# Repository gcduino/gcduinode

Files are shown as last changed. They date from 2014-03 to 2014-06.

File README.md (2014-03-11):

GCDuiNODE
=========

© 2014 Steve Dalton & Rod Christian

GCDuiNODE is a [GCDuino](https://github.com/gctechshop/gcduino) but running at 3.3V and includes a whole load of ports for  Networking modules. It was created by [Rod Christian](http://github.com/Rod-Refactor) and [Steve Dalton](http://github.com/spidie) of [Gold Coast TechSpace](http://gctechspace.org).

How to checkout this code
-------------------------

    git clone git@github.com:gctechshop/gcduinode.git

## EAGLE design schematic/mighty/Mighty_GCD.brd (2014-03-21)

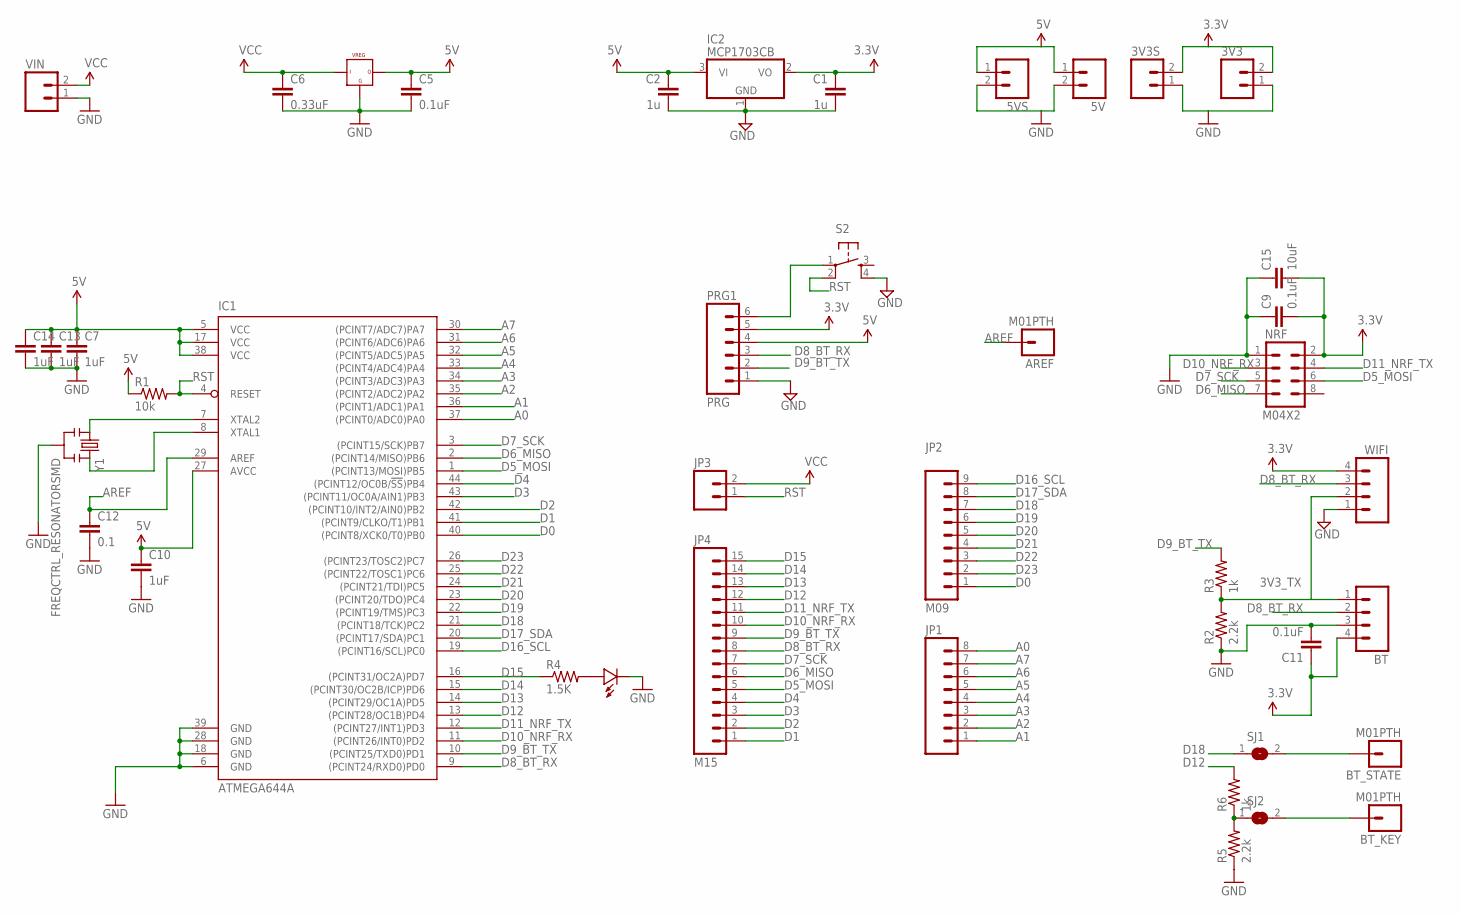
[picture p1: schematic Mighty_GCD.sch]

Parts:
3V3, 3V3S, 5V, 5VS: M02PTH; 1X02
AREF: M01PTH; 1X01
BT: M04PTH; 1X04
BT_KEY: M01PTH; 1X01
BT_STATE: M01PTH; 1X01
C1, C2: 1u; 0805
C5, C9, C11: 0.1uF; 0805
C6: 0.33uF; 0805
C7, C10, C13, C14: 1uF; 0805
C12: 0.1; 0805
C15: 10uF; 0805
IC1: ATMEGA644A; TQFP44
IC2: MCP1703CB; SOT23
JP1: M081X08; 1X08
JP2: M09; 1X09
JP3: M02PTH; 1X02
JP4: M15; 1X15
NRF: M04X2; 2X4
PRG1: PRG; 1X06
R1: 10k; 0805
R2, R5: 2.2k; 0805
R3, R6: 1k; 0805
R4: 1.5K; 0805
S2: TAC_SWITCHSMD; TACTILE_SWITCH_SMD
SJ1, SJ2: SJ
U$5: VREG_5V; DPACK
U$14: LED0805; 0805-LED
VIN: M02PTH; 1X02
WIFI: M04PTH; 1X04
Y1: FREQCTRL_RESONATORSMD; FREQCTRL_RESONATOR-SMD

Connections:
3.3V: 3V3.2, 3V3S.2, BT.4, C1.1, C9.2, C11.1, C15.2, IC2.2 (VO), NRF.2, PRG1.5, WIFI.4
3V3_TX: BT.1, R2.2, R3.1, WIFI.2
5V: 5V.1, 5VS.1, C2.1, C5.1, C7.1, C10.1, C13.1, C14.1, IC1.5 (VCC), IC1.17 (VCC), IC1.27 (AVCC), IC1.38 (VCC), IC2.3 (VI), PRG1.4, R1.1, U$5.3
A0: IC1.37 ((PCINT0/ADC0)PA0), JP1.8
A1: IC1.36 ((PCINT1/ADC1)PA1), JP1.1
A2: IC1.35 ((PCINT2/ADC2)PA2), JP1.2
A3: IC1.34 ((PCINT3/ADC3)PA3), JP1.3
A4: IC1.33 ((PCINT4/ADC4)PA4), JP1.4
A5: IC1.32 ((PCINT5/ADC5)PA5), JP1.5
A6: IC1.31 ((PCINT6/ADC6)PA6), JP1.6
A7: IC1.30 ((PCINT7/ADC7)PA7), JP1.7
AREF: AREF.1, C12.1, IC1.29 (AREF)
D0: IC1.40 ((PCINT8/XCK0/T0)PB0), JP2.1
D1: IC1.41 ((PCINT9/CLKO/T1)PB1), JP4.1
D2: IC1.42 ((PCINT10/INT2/AIN0)PB2), JP4.2
D3: IC1.43 ((PCINT11/OC0A/AIN1)PB3), JP4.3
D4: IC1.44 ((PCINT12/OC0B/!SS!)PB4), JP4.4
D5_MOSI: IC1.1 ((PCINT13/MOSI)PB5), JP4.5, NRF.6
D6_MISO: IC1.2 ((PCINT14/MISO)PB6), JP4.6, NRF.7
D7_SCK: IC1.3 ((PCINT15/SCK)PB7), JP4.7, NRF.5
D8_BT_RX: BT.2, IC1.9 ((PCINT24/RXD0)PD0), JP4.8, PRG1.3, WIFI.3
D9_BT_TX: IC1.10 ((PCINT25/TXD0)PD1), JP4.9, PRG1.2, R3.2
D10_NRF_RX: IC1.11 ((PCINT26/INT0)PD2), JP4.10, NRF.3
D11_NRF_TX: IC1.12 ((PCINT27/INT1)PD3), JP4.11, NRF.4
D12: IC1.13 ((PCINT28/OC1B)PD4), JP4.12, R6.2
D13: IC1.14 ((PCINT29/OC1A)PD5), JP4.13
D14: IC1.15 ((PCINT30/OC2B/ICP)PD6), JP4.14
D15: IC1.16 ((PCINT31/OC2A)PD7), JP4.15, R4.1
D16_SCL: IC1.19 ((PCINT16/SCL)PC0), JP2.9
D17_SDA: IC1.20 ((PCINT17/SDA)PC1), JP2.8
D18: IC1.21 ((PCINT18/TCK)PC2), JP2.7, SJ1.1
D19: IC1.22 ((PCINT19/TMS)PC3), JP2.6
D20: IC1.23 ((PCINT20/TDO)PC4), JP2.5
D21: IC1.24 ((PCINT21/TDI)PC5), JP2.4
D22: IC1.25 ((PCINT22/TOSC1)PC6), JP2.3
D23: IC1.26 ((PCINT23/TOSC2)PC7), JP2.2
GND: 3V3.1, 3V3S.1, 5V.2, 5VS.2, BT.3, C1.2, C2.2, C5.2, C6.2, C7.2, C9.1, C10.2, C11.2, C12.2, C13.2, C14.2, C15.1, IC1.6 (GND), IC1.18 (GND), IC1.28 (GND), IC1.39 (GND), IC2.1 (GND), NRF.1, PRG1.1, R2.1, R5.1, S2.4, U$5.2, U$14.MINUS, VIN.1, WIFI.1, Y1.2
unnamed: R4.2, U$14.PLUS
unnamed: IC1.7 (XTAL2), Y1.1
unnamed: IC1.8 (XTAL1), Y1.3
unnamed: PRG1.6, S2.1
unnamed: BT_STATE.1, SJ1.2
unnamed: BT_KEY.1, SJ2.2
unnamed: R5.2, R6.1, SJ2.1
RST: IC1.4 (RESET), JP3.1, R1.2, S2.2
VCC: C6.1, JP3.2, U$5.1, VIN.2

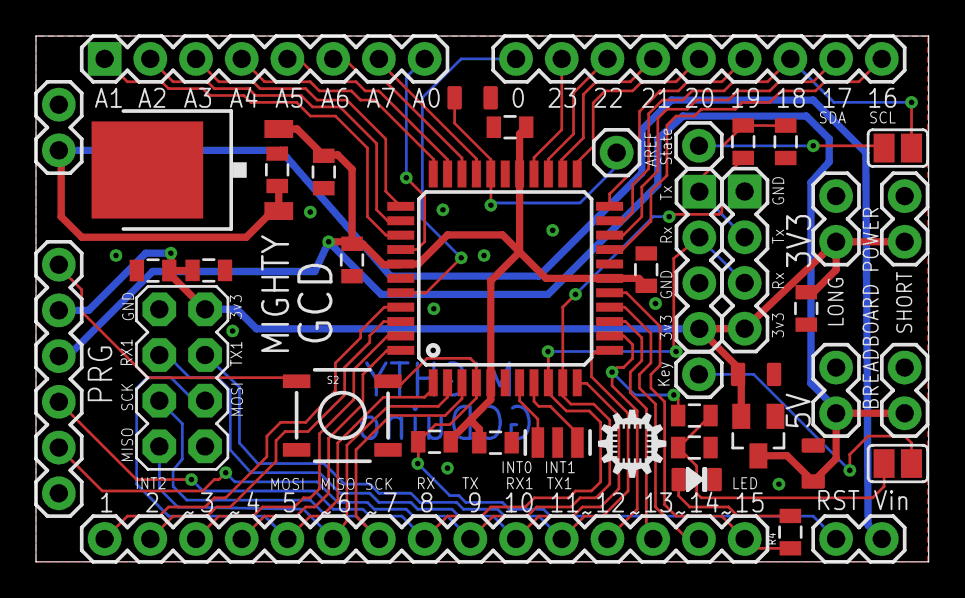
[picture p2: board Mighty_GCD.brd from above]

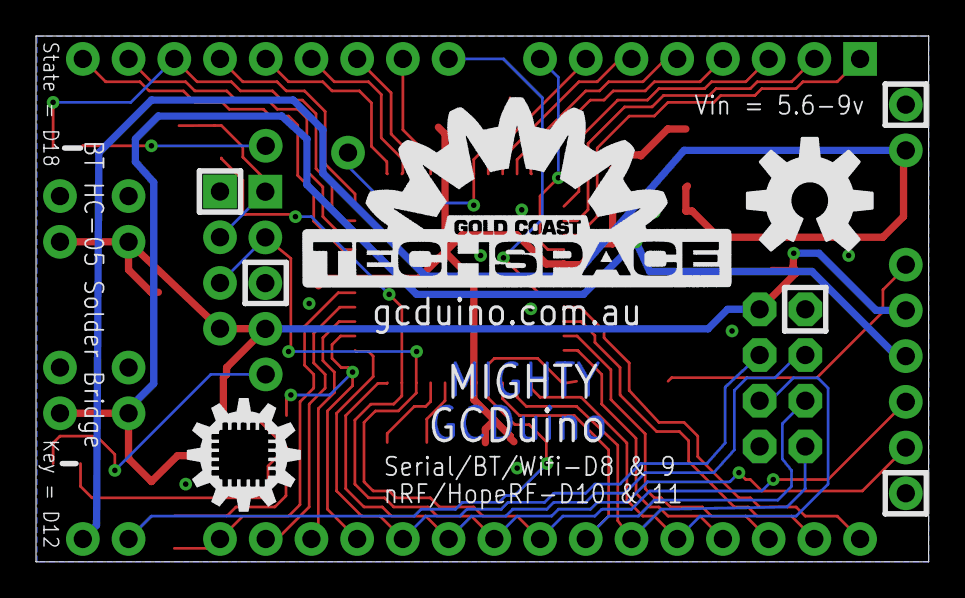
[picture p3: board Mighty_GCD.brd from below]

Board: 2 copper layers, 49.6 x 29.2 mm, 46 parts (3 on the bottom side), 46 nets.

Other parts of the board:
U$1: ID_LOGO_X0.25
U$2: GCTS_X0.5_TSILK
U$3: OSHW-LOGO-L
U$4: ID_LOGO_X0.15

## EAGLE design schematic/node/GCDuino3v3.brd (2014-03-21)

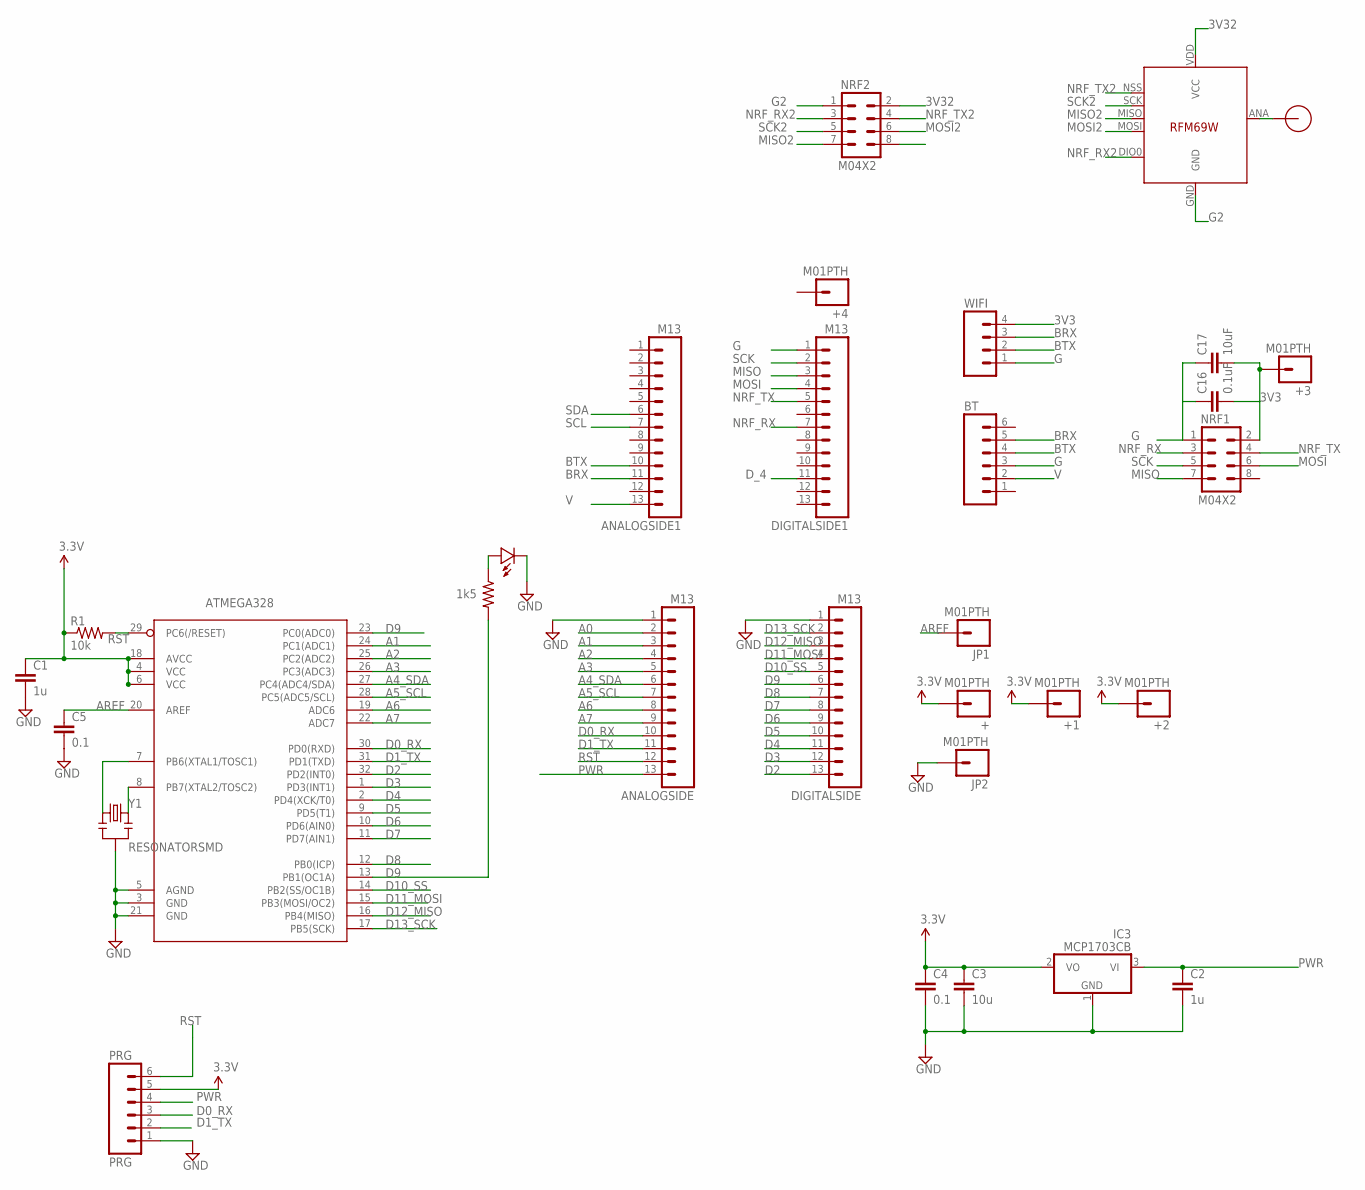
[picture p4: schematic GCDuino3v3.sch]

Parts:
+, +1, +2, +3, +4: M01PTH; 1X01
ANALOGSIDE, ANALOGSIDE1: M13; 1X13
ATMEGA328: ATMega-328; TQFP32-08
BT: M06SIP; 1X06
C1, C2: 1u; 0805
C3: 10u; 0805-CAP
C4, C5: 0.1; 0805
C16: 0.1uF; 0805
C17: 10uF; 0805
DIGITALSIDE, DIGITALSIDE1: M13; 1X13
IC3: MCP1703CB; SOT23
JP1, JP2: M01PTH; 1X01
NRF1, NRF2: M04X2; 2X4
PRG: PRG; 1X06
R1: 10k; 0805
R2: 1k5; 0805
U$2: LED0805; 0805-LED
U$5: RFM69; RFM69W-MINPADS
U$8: RFM12B_ANTENNA; RFM12B-ANTENNA
WIFI: M04PTH; 1X04
Y1: RESONATORSMD; RESONATOR-SMD

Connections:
3.3V: +.1, +1.1, +2.1, ATMEGA328.4 (VCC), ATMEGA328.6 (VCC), ATMEGA328.18 (AVCC), C1.1, C3.1, C4.1, IC3.2 (VO), PRG.5, R1.1
3V3: +3.1, C16.2, C17.2, NRF1.2, WIFI.4
3V32: NRF2.2, U$5.VDD (VCC)
A0: ANALOGSIDE.2, ATMEGA328.23 (PC0(ADC0))
A1: ANALOGSIDE.3, ATMEGA328.24 (PC1(ADC1))
A2: ANALOGSIDE.4, ATMEGA328.25 (PC2(ADC2))
A3: ANALOGSIDE.5, ATMEGA328.26 (PC3(ADC3))
A4_SDA: ANALOGSIDE.6, ATMEGA328.27 (PC4(ADC4/SDA))
A5_SCL: ANALOGSIDE.7, ATMEGA328.28 (PC5(ADC5/SCL))
A6: ANALOGSIDE.8, ATMEGA328.19 (ADC6)
A7: ANALOGSIDE.9, ATMEGA328.22 (ADC7)
AREF: ATMEGA328.20 (AREF), C5.1, JP1.1
BRX: ANALOGSIDE1.11, BT.5, WIFI.3
BTX: ANALOGSIDE1.10, BT.4, WIFI.2
D0_RX: ANALOGSIDE.10, ATMEGA328.30 (PD0(RXD)), PRG.3
D1_TX: ANALOGSIDE.11, ATMEGA328.31 (PD1(TXD)), PRG.2
D2: ATMEGA328.32 (PD2(INT0)), DIGITALSIDE.13
D3: ATMEGA328.1 (PD3(INT1)), DIGITALSIDE.12
D4: ATMEGA328.2 (PD4(XCK/T0)), DIGITALSIDE.11
D5: ATMEGA328.9 (PD5(T1)), DIGITALSIDE.10
D6: ATMEGA328.10 (PD6(AIN0)), DIGITALSIDE.9
D7: ATMEGA328.11 (PD7(AIN1)), DIGITALSIDE.8
D8: ATMEGA328.12 (PB0(ICP)), DIGITALSIDE.7
D9: ATMEGA328.13 (PB1(OC1A)), DIGITALSIDE.6, R2.2
D10_SS: ATMEGA328.14 (PB2(SS/OC1B)), DIGITALSIDE.5
D11_MOSI: ATMEGA328.15 (PB3(MOSI/OC2)), DIGITALSIDE.4
D12_MISO: ATMEGA328.16 (PB4(MISO)), DIGITALSIDE.3
D13_SCK: ATMEGA328.17 (PB5(SCK)), DIGITALSIDE.2
D_4: DIGITALSIDE1.11
G: BT.3, C16.1, C17.1, DIGITALSIDE1.1, NRF1.1, WIFI.1
G2: NRF2.1, U$5.GND
GND: ANALOGSIDE.1, ATMEGA328.3 (GND), ATMEGA328.5 (AGND), ATMEGA328.21 (GND), C1.2, C2.2, C3.2, C4.2, C5.2, DIGITALSIDE.1, IC3.1 (GND), JP2.1, PRG.1, U$2.MINUS, Y1.2
MISO: DIGITALSIDE1.3, NRF1.7
MISO2: NRF2.7, U$5.MISO
MOSI: DIGITALSIDE1.4, NRF1.6
MOSI2: NRF2.6, U$5.MOSI
unnamed: ATMEGA328.7 (PB6(XTAL1/TOSC1)), Y1.1
unnamed: R2.1, U$2.PLUS
unnamed: U$5.ANA (ANT), U$8.P$1
unnamed: ATMEGA328.8 (PB7(XTAL2/TOSC2)), Y1.3
NRF_RX: DIGITALSIDE1.7, NRF1.3
NRF_RX2: NRF2.3, U$5.DIO0
NRF_TX: DIGITALSIDE1.5, NRF1.4
NRF_TX2: NRF2.4, U$5.NSS (SEL)
PWR: ANALOGSIDE.13, C2.1, IC3.3 (VI), PRG.4
RST: ANALOGSIDE.12, ATMEGA328.29 (PC6(/RESET)), PRG.6, R1.2
SCK: DIGITALSIDE1.2, NRF1.5
SCK2: NRF2.5, U$5.SCK
SCL: ANALOGSIDE1.7
SDA: ANALOGSIDE1.6
V: ANALOGSIDE1.13, BT.2

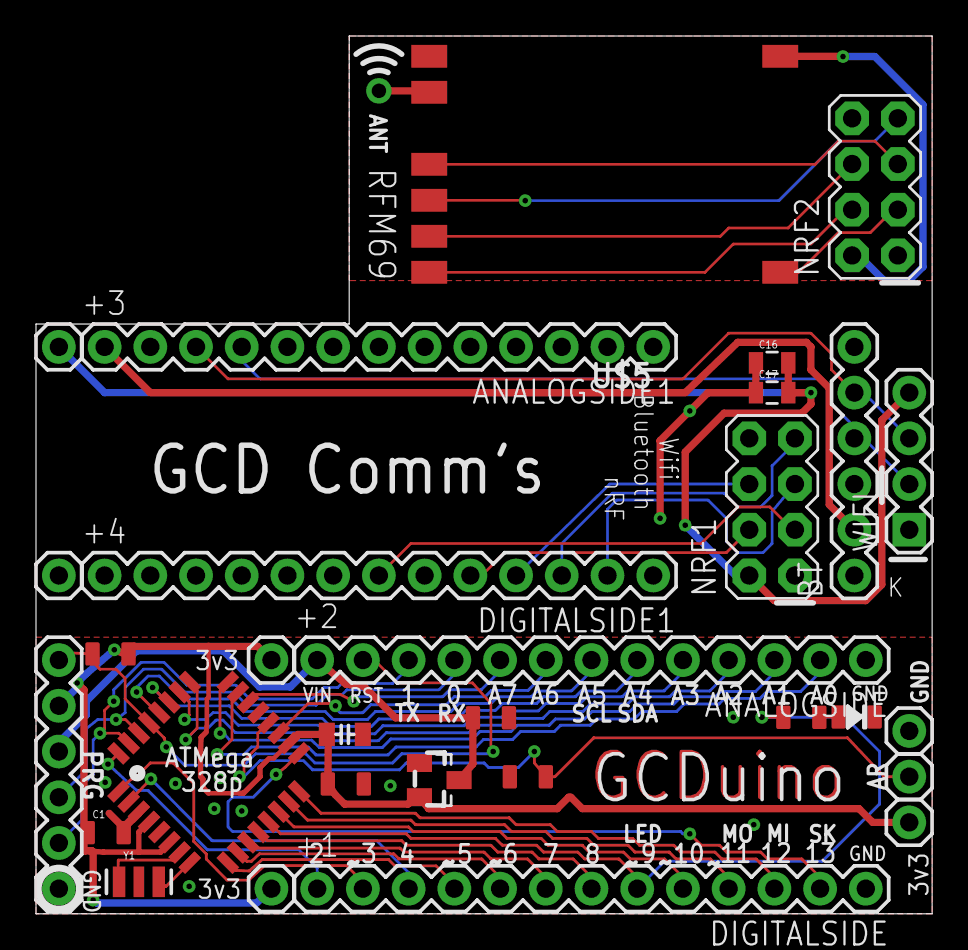
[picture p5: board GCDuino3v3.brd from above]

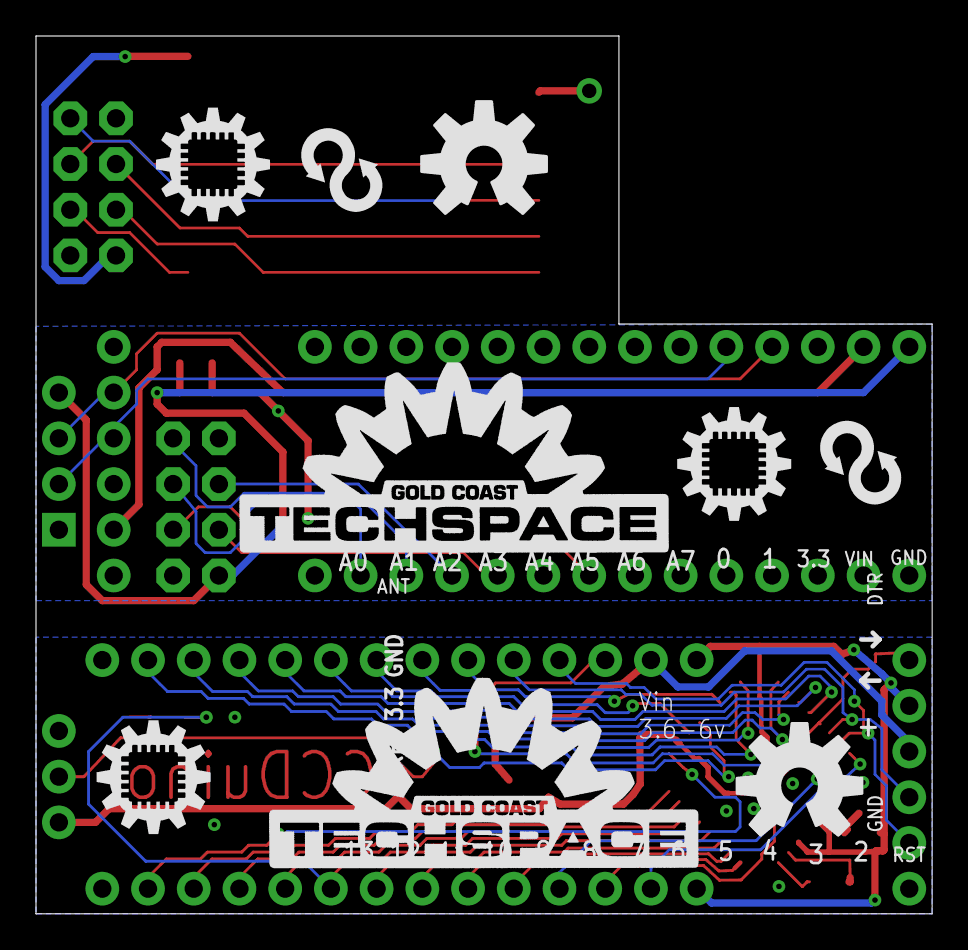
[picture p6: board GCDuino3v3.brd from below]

Board: 2 copper layers, 49.8 x 48.8 mm, 40 parts (9 on the bottom side), 48 nets.

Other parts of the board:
U$1, U$6, U$10: ID_LOGO_X0.25
U$3, U$12: REFACTORLOOP
U$4, U$9: GCTS_X0.5_TSILK
U$7, U$11: OSHW-LOGO-L

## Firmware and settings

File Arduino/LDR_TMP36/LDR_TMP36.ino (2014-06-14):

/* This is the base Code for the GCDuiNODEs on my Home nRF24L01+ sensor network.
*********************Writen By Rod Christian of GCDuino.com*************************
**                                                                                **
** It Use's Arduino's Low Power and Sleep Modes to conserve, monitor battery life **
**  You can Choose if you'd like it to wake via a Interrupt, a Reset or Watchdog  **
**                                                                                **
**   To use the internal Battery Monitor you must power the NODE directly, Not    **
**     Through the voltage regulator, so keep the voltage between 2.8v * 5v       **
**                                                                                **
**          You can also remove the Vreg to reduce current consumption            **
**    It's possible to Power sensors from spare pins, so you can turn them off    **
**    Remember each pin can only supply 40mA with a 250mA maximum for the NODE    **
**                                                                                **
******************************************************************16/05/2014*******/
//TODO: Test the Power Usage
//      Send converted data using an INT and shifting it. eg 25.78 = 2578
//      Write/Read the message number to EEPROM << NOPE get last message number from Base Station on startup!
//      Write example's for different sensors/functions
//      Automatically Get NODE Address from Base Station and write to EEPROM
//      Can we wake from receiving a message on the nRF if it's not asleep?
//      Turn This into A NODE Library!

//Included Libraries
#include <SPI.h>
#include <nRF24L01.h> // Writen by Maniacbug of http://maniacbug.wordpress.com/
#include <RF24.h>
#include <avr/sleep.h>

//Pin Defines
#define nRF_Rx    2   // nRF Rx
#define nRF_Tx    10  // nRF Tx
#define LED       9   // Onboard LED
#define INT1      3   //Button on INT1 connecting to Ground
#define tempPin   A7   //TMP36 Data
#define tempPwr   8   //TMP36 Power
#define lightPin  A6   //        A6    LDR-10k voltage divider Data
#define lightPwr  7   //pin7-LDR-^-10k-Gnd

//Variable
#define nodeAddress 3  //1 is ALWAYS Base Station
//Low Power Sleep Types in Order of Battery Ussage
#define resetableSleep 0      //Run's code, then goes to sleep waiting to be reset (eg, button,leverswitch etc) Will need to get msgNumber
#define interruptableSleep 1  //Relies on an interrupt on INT1 going low (eg. RTC) 
#define watchDogSleep 2       //Relies on the internal watchDog timer to wake the CPU

byte sleepType = watchDogSleep;  //Set the Sleep Type

//WATCHDOG SLEEP SETTINGS
#define interval 5 // Interval in minutes between waking and doing tasks
const int sleep_total = (interval*60)/8; // Approximate number 
// of sleep cycles needed before the interval defined above 
// elapses. Not that this does integer math ((interval*seconds)/8 Second Watchdog int)
volatile int sleep_count = 0; // Keep track of how many sleep cycles have been completed

RF24 radio(nRF_Rx, nRF_Tx);
const uint64_t pipes[2] = { 0xF0F0F0F0E1LL, 0xF0F0F0F0D2LL }; // Radio pipe addresses for the 2 nodes to communicate.

//ONLY WORKS IF THE BATTERY IS CONNECTED DIRECTLY TO THE CPU. Not using a voltage reg.
const long InternalReferenceVoltage = 1075;  // Adjust this value to your board's specific internal BandGap voltage
//Look in the Low_power Tab for this and Goto www.gcduino.com/*********** to find out more.
// 1093 = Breadboard NODE with 3v3 Reg, 1075 NODE no reg

//nRF Message Structure
typedef struct {
  int msgNumber;
  byte sender;
  byte sensor;
  int data;
  int batLevel;  //Do we use this as Sensor 1???? and then report how many messages will be coming
} 
message;
message msgToSend; 

long stopWatch = 0;

void setup() 
{       
  radio.begin();
  radio.setRetries(4,15);  // Set the delay between retries & # of retries
  //radio.setPayloadSize(6);  // Small payload size seems to improve reliability
  radio.setDataRate(RF24_2MBPS);  //RF24_250KBPS for 250kbs, RF24_1MBPS for 1Mbps, or RF24_2MBPS for 2Mbps
  radio.openWritingPipe(pipes[1]); //Become the transmitter (ping out)
  radio.stopListening();    

  // initialize the output LED.
  pinMode(LED, OUTPUT);    
  
  if(sleepType == interruptableSleep) digitalWrite(INT1, HIGH); //Enable the internal 10k Pull up resistor on the Interrupt Pin
  if(sleepType == watchDogSleep) watchdogOn(); // Turn on the watch dog timer.

  //Serial.begin(9600);  //For Debugging
  //Serial.println("Begin");  
  
  //Setup message Header
  msgToSend.msgNumber = 1;
  msgToSend.sender = nodeAddress;
  //Just to test!!!!
    sendData(1, tempPwr, tempPin);
    delay(5);
    sendData(2, lightPwr, lightPin);
}

void loop() //Always Transmits a message then sleeps
{
  
  //Serial.println(millis()); 
  //delay(500);
  if(sleepType == watchDogSleep) {
    //Serial.println(sleep_count);
    if(sleep_count >= sleep_total) {
      //Counts the amount of times the CPU has awaken from sleep
      // and transmits the data when it's reached the interval time.
      sendData(1, tempPwr, tempPin);    
      delay(5);
      sendData(2, lightPwr, lightPin);  
      sleep_count = 0;
    }
  } else {
    sendData(1, tempPwr, tempPin);
    delay(5);
    sendData(2, lightPwr, lightPin);
  } 
  gotoSleep(); 
}

void sendData(byte sensor, byte pwr, byte data){  //Convert to a function (powerPin, SensorPin)
  msgToSend.sensor = sensor;
  pinMode(pwr, OUTPUT); 
  digitalWrite(pwr, HIGH);
  delay(10);
  analogRead(data); //discharge the ADC capacitor
  delay(10);
  msgToSend.data = analogRead(data); 
  digitalWrite(pwr, LOW); 
  pinMode(pwr, INPUT); //Consumes less power as an INPUT
  //Battery Data
  msgToSend.batLevel = battVoltage();
  
  transmit();
}

//Unsure weather to do this in the NODE or in the BaseStation
void calcTemp(){ //Times by 100 to shift decimal and keep it Int Math, remember to shift decimal 1 place back
  //Rolls over change to long then cast to int!!
  int temp = (((analogRead(tempPin) *100 *330)/10240)-500);
  //eg TMP36 reading of 217 would equal 199 or 19.9 degress.
  //int volt = ((analogRead(data) *100 *330)/1024)-5000);  //to keep 2 decimal places eg 1993 or 19.93
}

void transmit()
{
  //Serial.println("Sending");
  //bool ok = radio.write( &data, sizeof(data) ); //Writes the data to the radio module
  bool ok = false;
  while(!ok) { 
  ok = radio.write( &msgToSend, sizeof(msgToSend) );
  //if (ok) Serial.println("OK"); //blinkLed(20);
  //else Serial.println("NOPE"); //blinkLed(100); //Turn LED on for an Error*/
  radio.startListening();  //Reset nRF after transmit
  delay(20);
  radio.stopListening(); 
  }
  msgToSend.msgNumber ++; 
  delay(200); //delay for testing and debounce
}


/*
void blinkLed(int time)
{
  for(int i = 0; i < 2; i++)  
  {
    digitalWrite(LED, HIGH); //Turn LED off for all OK
    delay(time);
    digitalWrite(LED, LOW); //Turn LED on for an Error
    delay(time);
  } 
}  */

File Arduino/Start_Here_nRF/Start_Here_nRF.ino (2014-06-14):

/*  This is the Hello World of GCDuiNODEs Communication, it's also great for range finding.
 *  Load this sketch onto 2 NODE's, changing the MODE on each of them.
 *  the LED will flash slow on both if they are sending/receiving messages, fast if they aren't.
 
 * Or... 
 * Leave one plugged into your PC with Serial monitor open, plug a bluetooth module & battery pack into the other.
 * Connect to it using the free android app Bluetooth spp pro (default pin of 1234) and enter it's byte steam mode.
 * You should see the char your transmitting come up repeatedly, when all you see is a string of "." your out of range.  */

boolean mode = 1; //0 = Transmit, 1 = Receive

#include <SPI.h>
#include "nRF24L01.h"  
#include "RF24.h"
// The above libraries were writen by Maniacbug of http://maniacbug.wordpress.com/

// Set up nRF24L01 radio on SPI bus plus pins 2 & 10 
RF24 radio(2, 10);

// Radio pipe addresses for the 2 nodes to communicate.
const uint64_t pipes[2] = { 0xF0F0F0F0E1LL, 0xF0F0F0F0E2LL };   

char recvChar;

#define LED 9

void setup()
{
  radio.begin();
  radio.setRetries(4,15);  // Set the delay between retries(per 250uS) & # of retries
  //radio.setPayloadSize(2);  // A smaller payload size improves reliability, set it for what you need
  radio.setDataRate(RF24_2MBPS);  // Set the Speed RF24_250KBPS for 250kbs, RF24_1MBPS for 1Mbps, or RF24_2MBPS for 2Mbps
  radio.openReadingPipe(1,pipes[1]);  //Listen on Radio Pipe(channel) 1
  radio.startListening(); 

  pinMode(LED, OUTPUT);
  digitalWrite(LED, HIGH);  //Blink to say we are alive
  delay(25);
  digitalWrite(LED, LOW);

  Serial.begin(9600); //For Debugging & bluetooth 
  if(mode) Serial.println("Receiving!");
  else Serial.println("Transmitting!");
}


void loop()
{
  if(mode) chkRadio(); 
  else transmit('N'); //Transmits the char N
}

void transmit(char data)  //WHICH MODULE TO TRANSMIT TO, DATA TO SEND
{
  radio.openWritingPipe(pipes[1]);
  radio.stopListening();
  bool ok = false;
  do{
    ok = radio.write(&data, sizeof(data)); //Writes the data to the radio module
    if(!ok){
      Serial.print(".");      
      digitalWrite(LED, HIGH);
      delay(20);       
      digitalWrite(LED, LOW);
      delay(20);
    }
    radio.startListening();  //Reset nRF before next transmit
    delay(20);
    radio.stopListening();
  } 
  while(!ok);
  Serial.println(data);
  digitalWrite(LED, HIGH);  //Long blink to say we sent a message
  delay(250);
  digitalWrite(LED, LOW); 
  delay(250);  
}

void chkRadio()
{
  if (radio.available())
  {
    bool done = false;    
    while (!done)
    {
      // Fetch the payload, and see if this was the last one.
      done = radio.read( &recvChar, sizeof(recvChar) );   
      delay(20);      
    }
    Serial.println(recvChar);
    radio.stopListening();
    radio.startListening();//RESET
    digitalWrite(LED, HIGH);  //Long blink to say we got a message
    delay(250);
    digitalWrite(LED, LOW);
    delay(250);
  }  
  else
  {
    digitalWrite(LED, HIGH);  //Short blink to say NO message
    Serial.print(".");
    delay(20);
    digitalWrite(LED, LOW);
    delay(20);
  } 
}

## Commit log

2014-03-21 added schematic
    [GCDuino3v3.brd, GCDuino3v3.sch]
2014-03-21 added mighty
    [GCDuino3v3.brd, GCDuino3v3.sch, Mighty_GCD.brd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]

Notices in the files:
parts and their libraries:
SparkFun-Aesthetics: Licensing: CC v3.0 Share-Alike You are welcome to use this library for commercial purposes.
